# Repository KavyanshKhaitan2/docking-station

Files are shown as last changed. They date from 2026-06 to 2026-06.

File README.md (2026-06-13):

# (Overengineered) Laptop Docking Station!

  

  [View in OnShape](https://cad.onshape.com/documents/6c290d74c1d15daba79eec04/w/3858ccf09c2f651529fab3b7/e/cec4245d48316d051146b3ca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)

A very cool laptop docking station with 9 USB-A 2.0 ports!

<div id="contents">

1. [Why?](#why)
2. [What can it do?](#what-can-it-do)
3. [Fallout Zine](#fallout-zine)
4. [PCB](#pcb)
   - [Mainboard](#mainboard)
   - [Left Daughterboard](#left-daugtherboard)
5. [Schematic](#schematic)
   - [Mainboard](#mainboard-1)
   - [Left Daughterboard](#left-daugtherboard-1)
   - [Right Daugtherboard](#right-daugtherboard)
   - [Front Daugtherboard](#front-daughterboard)
6. [3D](#3d)
   - [Main case](#main-case)
   - [Macropad assembly](#macropad-assembly)
   - [Macropad case](#macropad-case)
   - [ePaper assembly](#epaper-assembly)
   - [ePaper case](#epaper-case)
7. [Bill of Materials](#bom)

</div>

## Why?
My laptop only has 2 USB-A ports, which is honestly not enough especially when both of them are used up for a keyboard and mouse.

I made this docking station to change that.

Another reason I made this is that I kinda like taking my laptop with me and keep it on my lap while using it on the sofa sometimes, so a docking station kinda makes that easier so you only have to plug it in and then everything works!

<div align="center"><a href="#contents">Jump to contents</a></div>

## What can it do?
It has 9 USB ports, which you can connect whatever you want to. The USB ports are controlled using an Fe1.1s controller.

It also has an ESP32 and 2 controllable PWM case fans (with two mosfet so you can turn them completely off), to keep your laptop cool and prevent it from overheating.

I also added external power from a barrel jack, because the laptop wont be able to power so many USB ports, especially when things are connected to them.

There is also a programmable e-ink display, you can display the time, your notifications, the current speed of the fans, or even show specifically which USB ports are currently in use!

I also added a mini detachable macropad with three switches and a rotary encoder.

You can program the macropad's buttons to do whatever you want! The rotary encoder also works as a switch, so technically there are four switches. You can make the rotary encoder change the volume, fan speeds, etc!

The macropad is connected to the ESP32!

Oh and btw the ESP32 also supports WiFi incase you want it to show weather or something even when the laptop is turned off.

The ESP32 also knows exactly which ports are connected to devices at a time, so you can also make it show how many ports are in use, and how many are free, etc!

<div align="center"><a href="#contents">Jump to contents</a></div>

## Fallout Zine
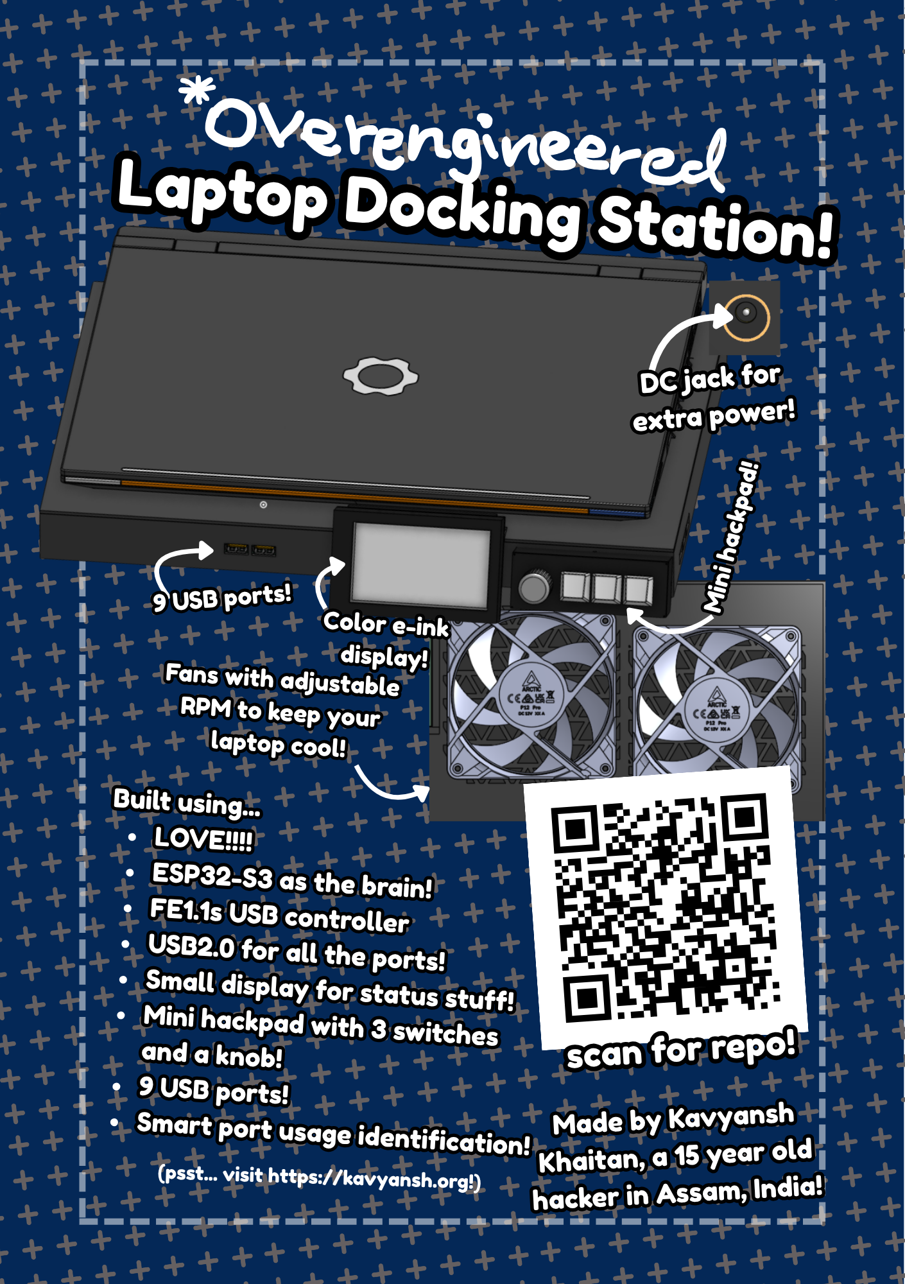
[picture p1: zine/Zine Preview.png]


[ [Download PDF](https://github.com/KavyanshKhaitan2/docking-station/raw/main/zine/Zine%20Print.pdf) ]

<div align="center"><a href="#contents">Jump to contents</a></div>

## PCB
<div align="center"><a href="https://kicanvas.org/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">View in KiCanvas</a></div>

### Mainboard


### Left Daugtherboard


The rest of the PCBs are very similar to the left daughterboard one, so I wont add them. If you still want to take a look at them, feel free to open the KiCanvas link!

<div align="center"><a href="#contents">Jump to contents</a></div>

## Schematic
<div align="center"><a href="https://kicanvas.org/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">View in KiCanvas</a></div>

### Mainboard


### Left daugtherboard


### Right daugtherboard


### Front daughterboard


<div align="center"><a href="#contents">Jump to contents</a></div>

## 3D
- [ [Download assembly as a STEP file](https://github.com/KavyanshKhaitan2/docking-station/blob/main/Final%20assembly.step) ]
- [ [Open Assembly in OnShape](https://cad.onshape.com/documents/6c290d74c1d15daba79eec04/w/3858ccf09c2f651529fab3b7/e/cec4245d48316d051146b3ca) ]

### Main case


- [View in OnShape](https://cad.onshape.com/documents/6c290d74c1d15daba79eec04/w/3858ccf09c2f651529fab3b7/e/84ca16973cb290fcea814d7e)
  - Part 1 (bottom) ([View STL in GitHub](https://github.com/KavyanshKhaitan2/docking-station/blob/main/production/3dp/Main%20Case/Main%20Case%20Thingy%20-%20Part%201.stl))
    - Print in black
    - Please print this part with supports!
  - Part 2 (top) ([View STL in GitHub](https://github.com/KavyanshKhaitan2/docking-station/blob/main/production/3dp/Main%20Case/Main%20Case%20Thingy%20-%20Part%202.stl))
    - Print in black

<div align="center"><a href="#contents">Jump to contents</a></div>

### Macropad assembly


- [View in OnShape](https://cad.onshape.com/documents/6c290d74c1d15daba79eec04/w/3858ccf09c2f651529fab3b7/e/eab1af3c6609ed024df62d84)

### Macropad case


- [View in OnShape](https://cad.onshape.com/documents/6c290d74c1d15daba79eec04/w/3858ccf09c2f651529fab3b7/e/cd5c69b8e6d2878261d109a7)
  - Part 1 (bottom) ([View STL in GitHub](https://github.com/KavyanshKhaitan2/docking-station/blob/main/production/3dp/Switches%20Case/Switches%20Case%20-%20Part%201.stl))
    - Print in black
  - Part 2 (top) ([View STL in GitHub](https://github.com/KavyanshKhaitan2/docking-station/blob/main/production/3dp/Switches%20Case/Switches%20Case%20-%20Part%202.stl))
    - Print in black
  - Screw ([View STL in GitHub](https://github.com/KavyanshKhaitan2/docking-station/blob/main/production/3dp/Switches%20Case/Switches%20Case%20-%20Screw%20(print%20x4).stl))
    - Print in black
    - Print x4
  - Accent (for top) ([View STL in GitHub](https://github.com/KavyanshKhaitan2/docking-station/blob/main/production/3dp/Switches%20Case/Switches%20Case%20-%20Accent.stl))
    - Print in filament closest to #8B2B2B.
      - 

<div align="center"><a href="#contents">Jump to contents</a></div>

### ePaper assembly


- [View in OnShape](https://cad.onshape.com/documents/6c290d74c1d15daba79eec04/w/3858ccf09c2f651529fab3b7/e/d050ad97f0686956ed070595)

### ePaper case


- Main part
  - [View in OnShape](https://cad.onshape.com/documents/6c290d74c1d15daba79eec04/w/3858ccf09c2f651529fab3b7/e/4e8279b7c40fa71bd8f46031)
  - Lid part (Lid) ([View STL in GitHub](https://github.com/KavyanshKhaitan2/docking-station/blob/main/production/3dp/ePaper%20Case/ePaper%20case%20-%20case-lid.stl))
  - Main part (Main) ([View STL in GitHub](https://github.com/KavyanshKhaitan2/docking-station/blob/main/production/3dp/ePaper%20Case/ePaper%20case%20-%20case-main.stl))
- Display angle-r
  - [View in OnShape](https://cad.onshape.com/documents/6c290d74c1d15daba79eec04/w/3858ccf09c2f651529fab3b7/e/b7b2b35c02b07108b093d455)
  - [View STL on GitHub](https://github.com/KavyanshKhaitan2/docking-station/blob/main/production/3dp/ePaper%20Case/Display%20angle-r%20-%20Part%201.stl)
    - Print in black
   
<div align="center"><a href="#contents">Jump to contents</a></div>

# BOM
The total BOM cost is ~167 USD.

- [ [View BOM.csv on GitHub](https://github.com/KavyanshKhaitan2/docking-station/blob/main/BOM.csv) ]
- [ [View BOM on Google Sheets (recommended)](https://docs.google.com/spreadsheets/d/10IkC0bF_AbRYA1OKs2MpRCw-cC0xSpxhRANUAgOrwtY/edit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) ]

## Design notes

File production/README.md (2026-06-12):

# Ordering PCBs
These gerber zip files were produced using JLCPCB Toolkit in KiCAD, so it is recommended to order the PCBs from JLCPCB.
- All green
- All 2 layer boards
- All 1.6mm thick

# Printing the 3D models
- The Main Case, which is split in 2 parts, is printed in all black.
- - You may need to use some supports to print it properly, in which case, please do!
- The ePaper case contains two sub-modules
- - The Display angle-r (to connect the ePaper case with the Main Case at an angle)
- - - This part can be printed sideways so its efficient.
- - The ePaper case (the actual case)
- - Both have to be printed in all black.
- Switches Case
- - The "Part 1" and "Part 2" parts are printed in all-black.
- - The "Screw" part has to be printed 4 times in all-black.
- - The "Accent" part has to be printed in the accent colored filament, which should ideally be closest to this hex color: #8B2B2B

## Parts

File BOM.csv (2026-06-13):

Item name | Description | Link | Unit Price (USD) | MOQ | Qty | Qty to order | Amount | Running total | Item for
TYPE-C-31-M-12 | Type C receptacle | https://www.lcsc.com/product-detail/C165948.html | 0.1870 | 5 | 2 | 5 | 0.9350 | 0.94 | Mainboard
DC022B | Barrel Jack receptacle | https://www.lcsc.com/product-detail/C668599.html | 0.1563 | 5 | 1 | 5 | 0.7815 | 1.72 | Mainboard
S3-WROOM-1-N8 | MCU module | https://www.lcsc.com/product-detail/C2913198.html | 4.7733 | 1 | 1 | 1 | 4.7733 | 6.49 | Mainboard
FE1.1s-BSOP28BCNTR | USB controller | https://www.lcsc.com/product-detail/C42383361.html | 0.7039 | 1 | 3 | 3 | 2.1117 | 8.60 | Mainboard
CL31B104KBCNNNC | 0.1uF 1206 cap | https://www.lcsc.com/product-detail/C97946.html | 0.0190 | 20 | 21 | 40 | 0.7600 | 9.36 | Mainboard
T49S12MLDBE2X | Crystal 12MHz 20pF | https://www.lcsc.com/product-detail/C19189932.html | 0.0754 | 10 | 3 | 10 | 0.7540 | 10.12 | Mainboard
RT1206BRD075KL | RES 5kΩ ±1% 1206 | https://www.lcsc.com/product-detail/C870818.html | 0.0635 | 10 | 3 | 10 | 0.6350 | 10.75 | Mainboard
FRC1206F2701TS | RES 2.7kΩ ±1% 1206 | https://www.lcsc.com/product-detail/C2930416.html | 0.0044 | 100 | 3 | 100 | 0.4400 | 11.19 | Mainboard
B3F-4005 | Tactile Switch | https://www.lcsc.com/product-detail/C397283.html | 0.1612 | 5 | 1 | 5 | 0.8060 | 12.00 | Mainboard
FRC1206F5101TS | RES 5.1kΩ ±1% 1206 | https://www.lcsc.com/product-detail/C2933721.html | 0.0042 | 100 | 4 | 100 | 0.4200 | 12.42 | Mainboard
LM1117F-3.3 | 3V3 @ 1A L.D.O | https://www.lcsc.com/product-detail/C126019.html | 0.1849 | 5 | 1 | 5 | 0.9245 | 13.34 | Mainboard
AMS1117-1.8V | 1V8 @ 1A L.D.O | https://www.lcsc.com/product-detail/C5120766.html | 0.0531 | 10 | 1 | 10 | 0.5310 | 13.87 | Mainboard
Arctic P12 Slim | Case fan | https://www.amazon.in/ARCTIC-P12-Slim-PWM-Pressure-optimised/dp/B08QDKGCCW | 10.0000 | 1 | 2 | 2 | 20.0000 | 33.87 | Mainboard
RC1206FR-0710KL | RES 10kΩ ±1% 1206 | https://www.lcsc.com/product-detail/C132649.html | 0.0053 | 100 | 2 | 100 | 0.5300 | 34.40 | Mainboard
IRLZ44N(UMW) | N-Channel MOSFET | https://www.lcsc.com/product-detail/C42370423.html | 0.3353 | 5 | 2 | 5 | 1.6765 | 36.08 | Mainboard
B9B-PH-K-S(LF)(SN) | For E-Ink display | https://www.lcsc.com/product-detail/C157968.html | 0.1182 | 5 | 2 | 5 | 0.5910 | 36.67 | Mainboard
3.7inch e-Paper HAT+ | E-Ink display | https://www.amazon.in/3-7inch-Resolution-Interface-Compatible-Raspberry/dp/B0FCMBNR46 | 72.0000 | 1 | 1 | 1 | 72.0000 | 108.67 | Mainboard
GRM188R71A225KE15D | CAP CER 2.2uF 10V X7R 0603 | https://www.lcsc.com/product-detail/C86018.html | 0.0461 | 20 | 1 | 20 | 0.9220 | 109.59 | Buck Converter
GRM155R71A104KA01D | CAP CER 100nF 10V X7R 0402 | https://www.lcsc.com/product-detail/C71687.html | 0.0045 | 100 | 2 | 100 | 0.4500 | 110.04 | Buck Converter
GRM21BR61A226ME44L | CAP CER 22uF 10V X5R 0805 | https://www.lcsc.com/product-detail/C441864.html | 0.1006 | 5 | 1 | 5 | 0.5030 | 110.54 | Buck Converter
FRC1206F1003TS | RES 100kΩ ±1% 250mW 1206 | https://www.lcsc.com/product-detail/C2907368.html | 0.0043 | 100 | 1 | 100 | 0.4300 | 110.97 | Buck Converter
XAL5020-561MEC | FIXED IND 560nH SMD,5.4x5.2mm | https://www.lcsc.com/product-detail/C20623488.html | 1.7578 | 1 | 1 | 1 | 1.7578 | 112.73 | Buck Converter
CSD17579Q5A | MOSFET N-CH 30V 46A VSONP-8(5x6) | https://www.lcsc.com/product-detail/C2760461.html | 0.4784 | 5 | 2 | 5 | 2.3920 | 115.12 | Buck Converter
GRM31CR71E335KA88L | CAP CER 3.3uF 25V X7R 1206 | https://www.lcsc.com/product-detail/C668366.html | 0.2513 | 5 | 2 | 5 | 1.2565 | 116.38 | Buck Converter
CSD17579Q5A | MOSFET N-CH 30V 46A VSONP-8(5x6) | https://www.lcsc.com/product-detail/C2760461.html | 0.4784 | 1 | 1 | 1 | 0.4784 | 116.86 | Buck Converter
LM5148RGYR | 80-V Synchronous Buck DC/DC Controller | https://www.lcsc.com/product-detail/C7470701.html | 0.9316 | 2 | 1 | 2 | 1.8632 | 118.72 | Buck Converter
1RC1206F9538 | 250mW 9.53Ω 200V Thick Film Resistor ±1% ±400ppm/℃ 1206 Chip Resistor - Surface Mount RoHS | https://www.lcsc.com/product-detail/C54533007.html | 0.0032 | 100 | 1 | 100 | 0.3200 | 119.04 | Buck Converter
WSLP12066L000FEA | RES 6mΩ ±1% 1W 1206 | https://www.lcsc.com/product-detail/C2090290.html | 0.1782 | 5 | 1 | 5 | 0.8910 | 119.93 | Buck Converter
FRC1206F4022TS | RES 40.2kΩ ±1% 250mW 1206 | https://www.lcsc.com/product-detail/C5159734.html | 0.0041 | 100 | 1 | 100 | 0.4100 | 120.34 | Buck Converter
06031U6R8BAT2A | 6.8pF 100V 0603 Ceramic Capacitors RoHS | https://www.lcsc.com/product-detail/C5259058.html | 0.2691 | 2 | 1 | 2 | 0.5382 | 120.88 | Buck Converter
CL21C222JBFNNNE | CAP CER 2.2nF 50V C0G 0805 | https://www.lcsc.com/product-detail/C28260.html | 0.0289 | 10 | 1 | 10 | 0.2890 | 121.17 | Buck Converter
FRC1206F2801TS | RES 2.8kΩ ±1% 250mW 1206 | https://www.lcsc.com/product-detail/C5126233.html | 0.0042 | 100 | 1 | 100 | 0.4200 | 121.59 | Buck Converter
FRC1206F2432TS | RES 24.3kΩ ±1% 250mW 1206 | https://www.lcsc.com/product-detail/C2933651.html | 0.0043 | 100 | 2 | 100 | 0.4300 | 122.02 | Buck Converter
MOLEX 2005280040 | CONN FFC FPC 4POS 1mm BOTTOM CNT SMD R/A | https://www.lcsc.com/product-detail/C563728.html | 0.2335 | 5 | 4 | 5 | 1.1675 | 123.19 | MB, LB, FB
AFA07-S06ECA-00 | CONN FFC FPC 6POS 1mm TOP CNT SMD R/A | https://www.lcsc.com/product-detail/C262733.html | 0.1105 | 5 | 2 | 5 | 0.5525 | 123.74 | MB, RB
USB1046-GF-0190-L-B-A | USB Receptacle, Type A, 4 Pin, SMT, Horizontal | https://www.lcsc.com/product-detail/C6307429.html | 0.8497 | 2 | 7 | 8 | 6.7976 | 130.54 | Mainboard
JS10B-04P-150-4-8 | CABLE FFC/FPC 4POS 1mm | https://www.lcsc.com/product-detail/C2857773.html | 0.1021 | 5 | 1 | 5 | 0.5105 | 131.05 | Left Board
JS10B-04P-150-4-8 | CABLE FFC/FPC 4POS 1mm | https://www.lcsc.com/product-detail/C2857773.html | 0.1021 | 5 | 1 | 5 | 0.5105 | 131.56 | Front Board
1.0*6P*400*B*4/4*8/8 | 0.3mm 6P 1mm Reverse 40cm P=1mm Flat Flex Cables (FFC, FPC) RoHS | https://www.lcsc.com/product-detail/C54350058.html | 0.0848 | 5 | 1 | 5 | 0.4240 | 131.98 | Right Board
PEC11R-4020F-S0024 | Through Hole Encoders RoHS | https://www.lcsc.com/product-detail/C143788.html | 3.1835 | 1 | 1 | 1 | 3.1835 | 135.17 | Front Panel
CPG151101D13 | Blue Switch 12V 50gf Through Hole Pushbutton Switches RoHS | https://www.lcsc.com/product-detail/C49234235.html | 0.1065 | 5 | 4 | 5 | 0.5325 | 135.70 | Front Panel
USB1046-GF-0190-L-B-A | USB Receptacle, Type A, 4 Pin, SMT, Horizontal | https://www.lcsc.com/product-detail/C6307429.html | 0.8497 | 2 | 2 | 2 | 1.6994 | 137.40 | Front Panel
2.54-1*4P | CONN SOCKET 4POS 2.54mm SINGLE ROW TH | https://www.lcsc.com/product-detail/C2718488.html | 0.0783 | 10 | 1 | 10 | 0.7830 | 138.18 | Front Panel
PM2.54-1X2PM-H85 | CONN SOCKET 2POS 2.54mm SINGLE ROW TH | https://www.lcsc.com/product-detail/C42431841.html | 0.0767 | 5 | 1 | 5 | 0.3835 | 138.57 | Front Panel
USB1046-GF-0190-L-B-A | USB Receptacle, Type A, 4 Pin, SMT, Horizontal | https://www.lcsc.com/product-detail/C6307429.html | 0.8497 | 2 | 2 | 2 | 1.6994 | 140.26 | Left Panel
USB1046-GF-0190-L-B-A | USB Receptacle, Type A, 4 Pin, SMT, Horizontal | https://www.lcsc.com/product-detail/C6307429.html | 0.8497 | 2 | 3 | 4 | 3.3988 | 143.66 | Right Panel
Power Cables | qty. in metres | https://robu.in/product/12awg-solid-core-insulated-wire-silicone-black/ | 1.5000 | 1 | 10 | 10 | 15.0000 | 158.66 | For power
PCBs | qty. in 5 PCBs | https://jlcpcb.com | 2.0000 | 1 | 4 | 4 | 8.0000 | 166.66 | Just PCBs lol

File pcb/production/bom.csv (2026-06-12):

Designator | Footprint | Quantity | Value | LCSC Part #
C1, C10, C11, C12, C13, C14, C15, C16, C18, C2, C24, C25, C29, C3, C4, C5, C6, C7, C8, C9 | 1206 | 20 | 0.1uF
C17 | 0603 | 1 | 2.2uF|9mΩ
C19, C23 | 1206 | 2 | 3.4uF|4.66mΩ
C20 | 0805 | 1 | 2.2nF
C21 | 0603 | 1 | 6.8pF
C22, C28 | 0402 | 2 | 100nF|1mΩ
C26 | 0805 | 1 | 22uF|3mΩ
J10 | JUSHUO_AFA07-S06FCA-00_1x6-1MP_P1.0mm_Horizontal | 1 | Conn_01x06
J11 | PinHeader_1x06_P2.54mm_Vertical | 1 | Conn_01x06
J15, J19 | USB_C_Receptacle_HRO_TYPE-C-31-M-12 | 2 | USB_C_Receptacle_USB2.0_16P
J2 | SolderWire-4sqmm_1x02_P12mm_D3mm_OD6mm | 1 | DC022B (external)
J20, J24, J27 | SolderWire-4sqmm_1x02_P12mm_D3mm_OD6mm | 3 | Conn_01x02
J21, J25 | Molex_200528-0040_1x04-1MP_P1.00mm_Horizontal | 2 | Conn_01x04
J4 | JST_PH_B9B-PH-K_1x09_P2.00mm_Vertical | 1 | Conn_01x09
J5, J7 | USB_A_Receptacle_GCT_USB1046 | 2 | USB_A
L2 | L_Coilcraft_XAL5020-XXX | 1 | 560nH|8.3mΩ
M1, M2 | FanPinHeader_1x04_P2.54mm_Vertical | 2 | Fan_4pin
Q1, Q2 | TDSON-8-1 | 2 | CSD17579Q5A
Q3, Q4 | TO-220-3_Vertical | 2 | IRLZ44N
R1, R6, R8 | 1206 | 3 | 2.7k±1%
R10 | 1206 | 1 | 24.3k
R11 | 1206 | 1 | 2.8k
R12 | 1206 | 1 | 6m
R13, R14 | 1206 | 2 | 10k
R15, R16, R17, R18, R21 | 1206 | 5 | 5.1k
R19, R20 | 1206 | 2 | 1k
R22, R5, R7 | 1206 | 3 | 5k±10%
R3 | 1206 | 1 | 40.2k
R4 | 1206 | 1 | 9.53k
R9 | 1206 | 1 | 100k
SW1 | SW_SPST_Omron_B3F-50xx | 1 | SW_SPST
U1, U5, U6 | SSOP-28_3.9x9.9mm_P0.635mm | 3 | FE1.1s
U2 | SOT-89-3_Handsoldering | 1 | LM1117F-3.3
U3 | SOT-89-3_Handsoldering | 1 | AMS1117-1.8
U4 | ESP32-S3-WROOM-1 | 1 | ESP32-S3-WROOM-1
U7 | Texas_RGY_R-PVQFN-N24_EP2.05x3.1mm_ThermalVias | 1 | LM5148RGYR
Y1, Y3, Y4 | Crystal_HC49-4H_Vertical | 3 | T49S12MLDBE2X

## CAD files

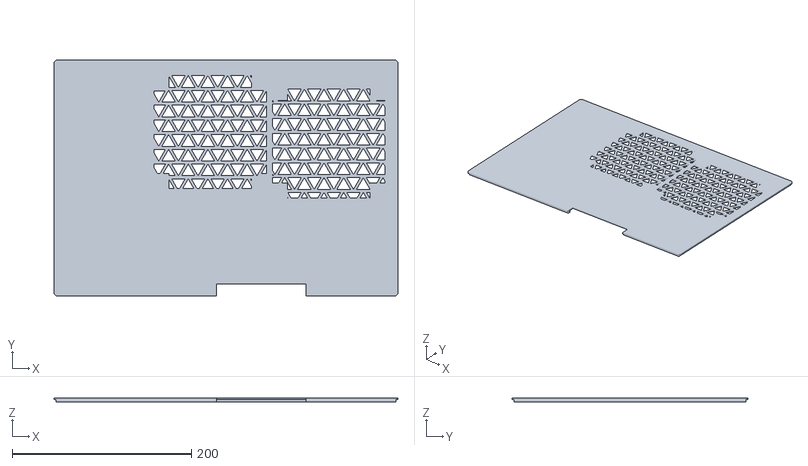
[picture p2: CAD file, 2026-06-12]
production/3dp/Main Case/Main Case Thingy - Part 2.stl
383.9 x 263.5 x 5.00

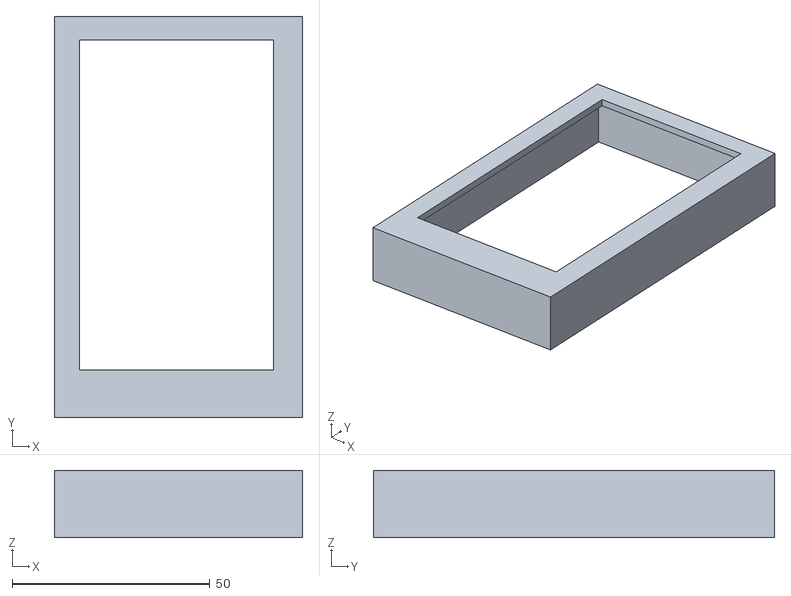
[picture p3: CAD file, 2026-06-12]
production/3dp/ePaper Case/ePaper case - case-main.stl
62.7 x 101.5 x 17.0

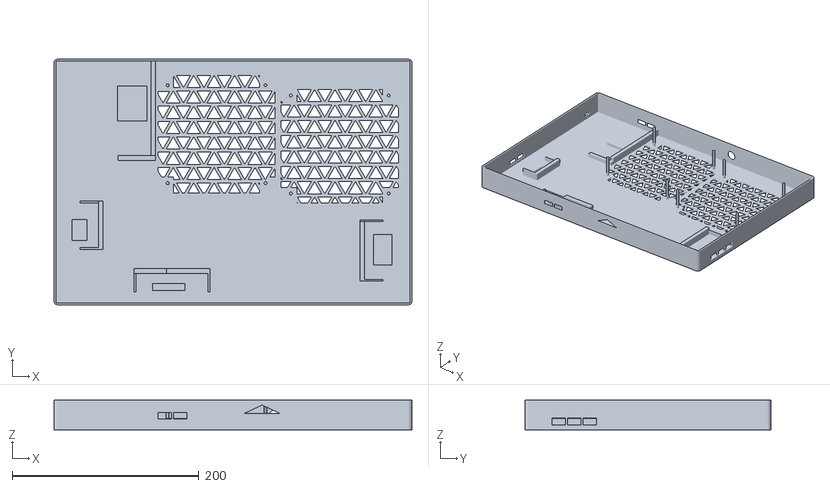
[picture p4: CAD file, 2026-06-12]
production/3dp/Main Case/Main Case Thingy - Part 1.stl
383.9 x 263.5 x 32.0

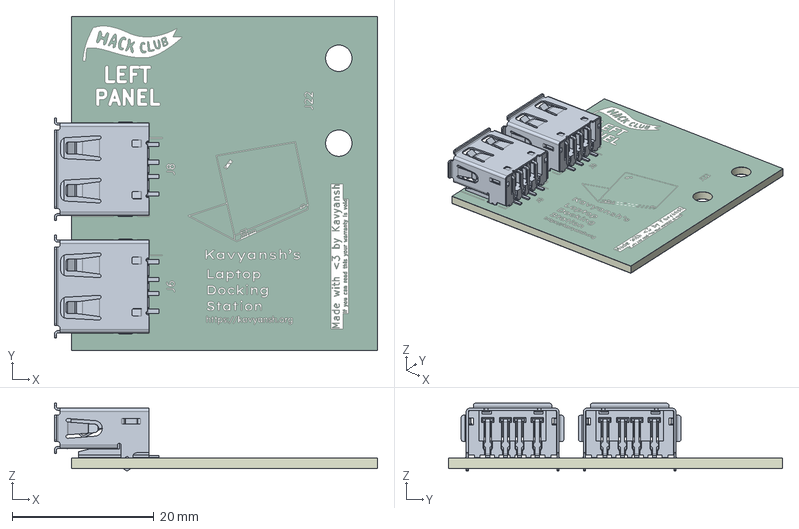
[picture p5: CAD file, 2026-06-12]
pcb/pcb_3dm/daughterboard-left.step
45.7 x 47.2 x 9.55 mm
USB1046-GF-0190-L-B-A_PART1 x 2
USB1046-GF-0190-L-B-A_PART2 x 2
USB1046-GF-0190-L-B-A_PART3 x 8
daughterboard-left_silkscreen x 2
daughterboard-left_soldermask x 2
daughterboard-left_PCB

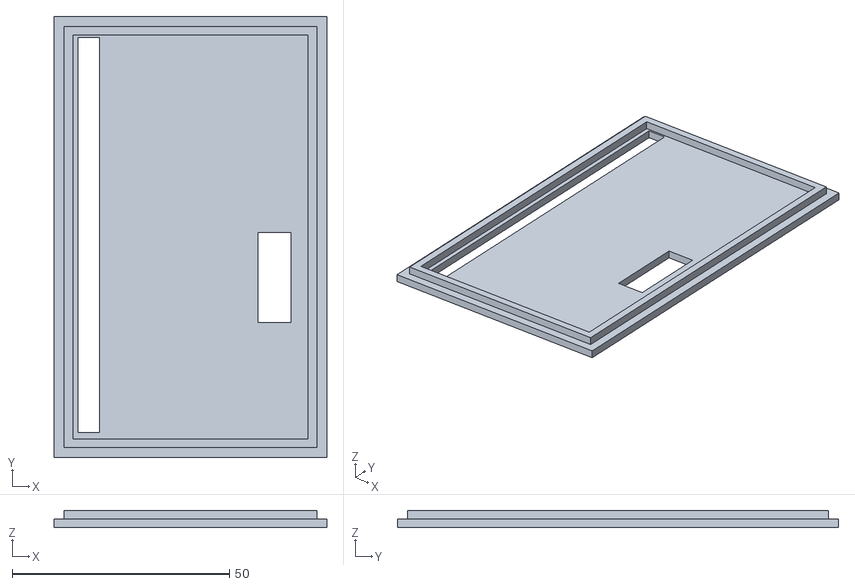
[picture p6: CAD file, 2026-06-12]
production/3dp/ePaper Case/ePaper case - case-lid.stl
62.7 x 101.5 x 4.00

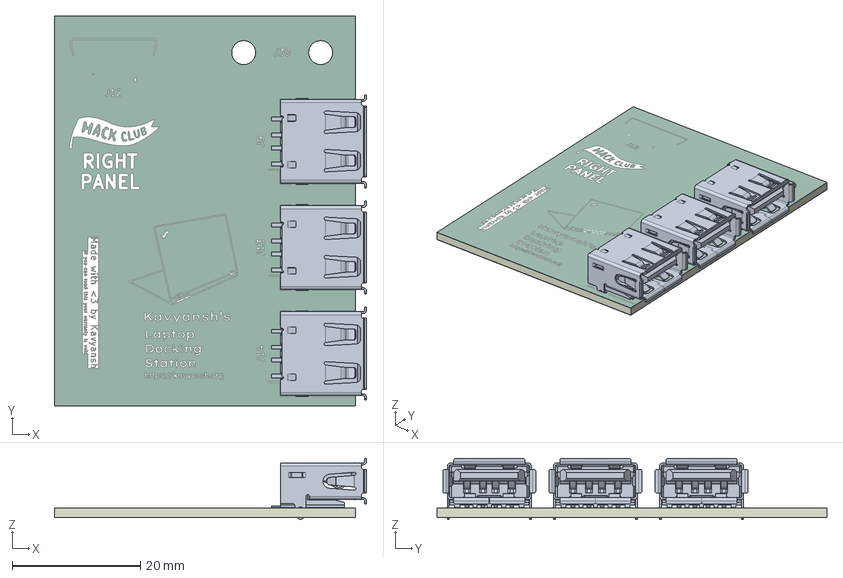
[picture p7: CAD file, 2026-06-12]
pcb/pcb_3dm/daughterboard-right.step
48.7 x 60.8 x 9.55 mm
USB1046-GF-0190-L-B-A_PART1 x 3
USB1046-GF-0190-L-B-A_PART2 x 3
USB1046-GF-0190-L-B-A_PART3 x 12
daughterboard-right_silkscreen x 2
daughterboard-right_soldermask x 2
daughterboard-right_PCB

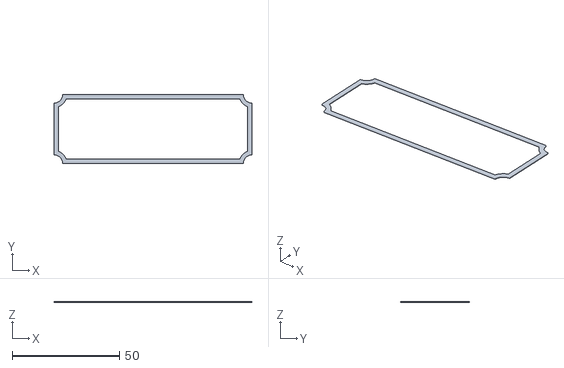
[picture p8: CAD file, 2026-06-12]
production/3dp/Switches Case/Switches Case - Accent.stl
92.2 x 32.1 x 0.5

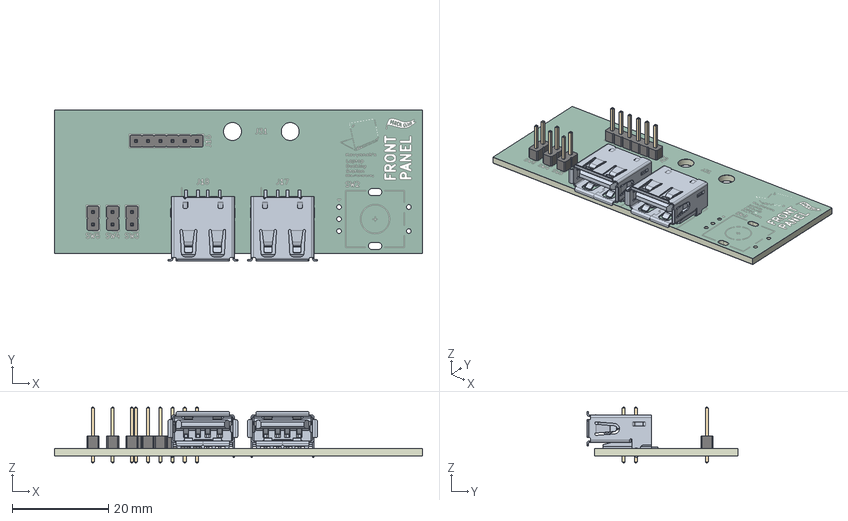
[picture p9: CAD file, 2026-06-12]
pcb/pcb_3dm/daughterboard-front.step
76.5 x 31.5 x 11.5 mm
PinHeader_1x02_P254mm_Vertical x 3
USB1046-GF-0190-L-B-A_PART1 x 2
USB1046-GF-0190-L-B-A_PART2 x 2
USB1046-GF-0190-L-B-A_PART3 x 8
PinHeader_1x06_P254mm_Vertical
daughterboard-front_silkscreen x 2
daughterboard-front_soldermask x 2
daughterboard-front_PCB

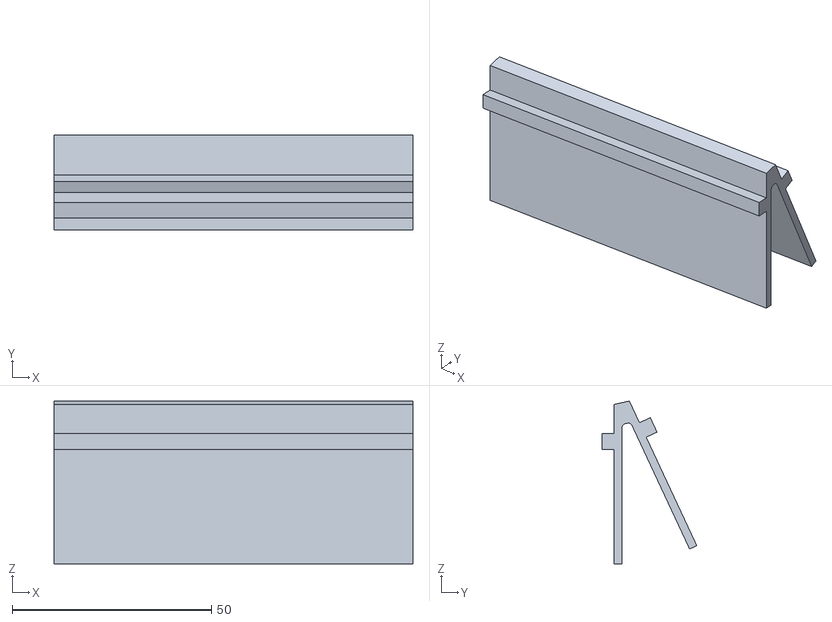
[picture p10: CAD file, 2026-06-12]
production/3dp/ePaper Case/Display angle-r - Part 1.stl
90.0 x 23.7 x 40.8

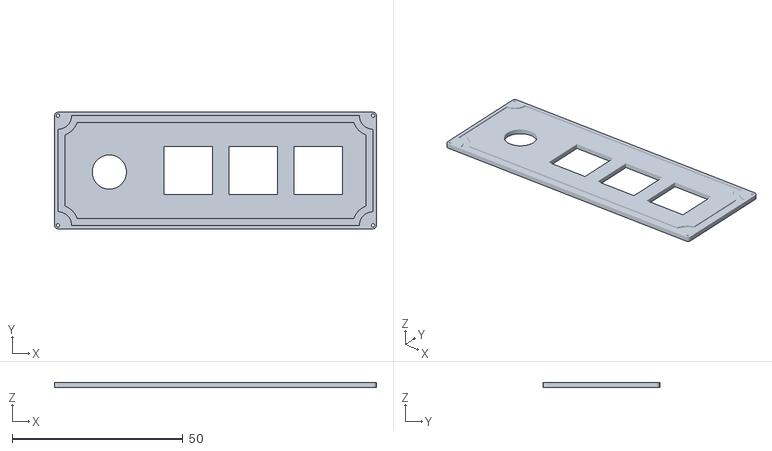
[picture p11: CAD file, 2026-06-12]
production/3dp/Switches Case/Switches Case - Part 2.stl
94.2 x 34.1 x 1.50

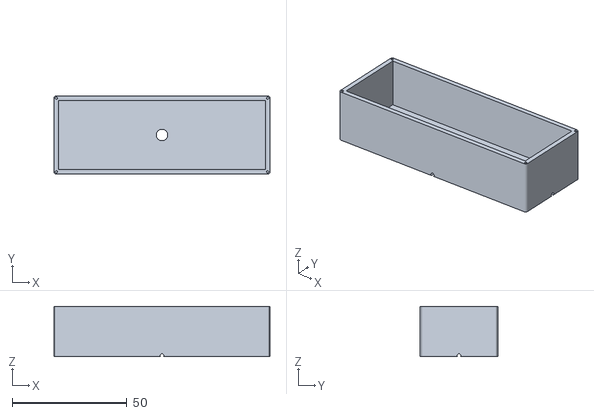
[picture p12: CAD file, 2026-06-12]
production/3dp/Switches Case/Switches Case - Part 1.stl
94.2 x 34.1 x 22.0

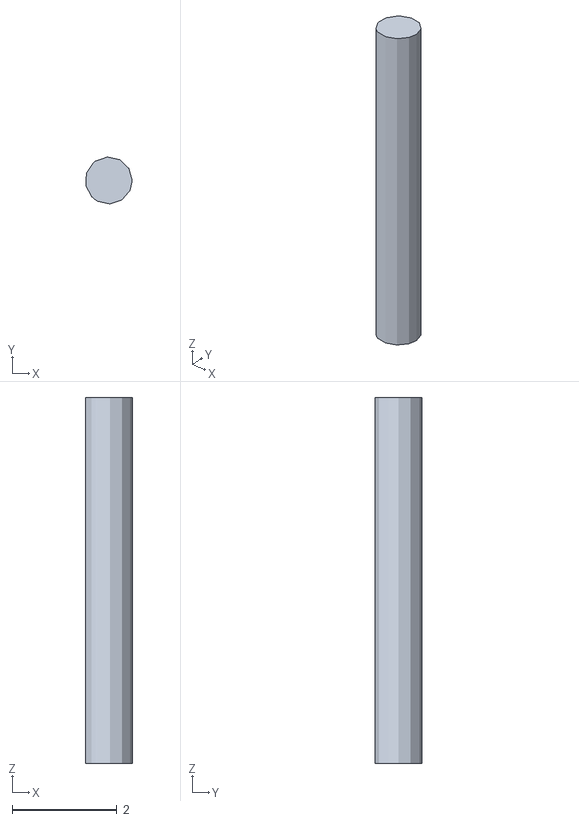
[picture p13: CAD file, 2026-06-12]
production/3dp/Switches Case/Switches Case - Screw (print x4).stl
0.889 x 0.899 x 7.00

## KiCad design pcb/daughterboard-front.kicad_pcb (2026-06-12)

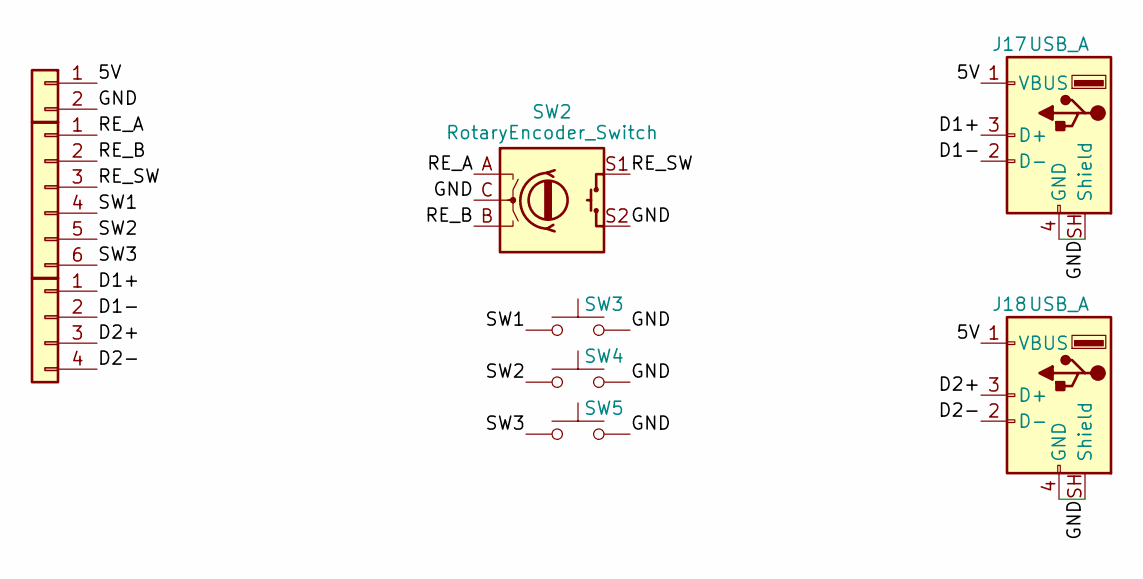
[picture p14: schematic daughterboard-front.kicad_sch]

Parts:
J16: Conn_01x06; PinHeader_1x06_P2.54mm_Vertical
J17, J18: USB_A; USB_A_Receptacle_GCT_USB1046
J26: Conn_01x04; Molex_200528-0040_1x04-1MP_P1.00mm_Horizontal
J31: Conn_01x02; SolderWire-4sqmm_1x02_P12mm_D3mm_OD6mm
SW2: RotaryEncoder_Switch; RotaryEncoder_Alps_EC11E-Switch_Vertical_H20mm
SW3, SW4, SW5: SW_Push; PinHeader_1x02_P2.54mm_Vertical

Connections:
/5V: J17.1 (VBUS), J18.1 (VBUS), J31.1
/D1+: J17.3 (D+), J26.1
/D1-: J17.2 (D-), J26.2
/D2+: J18.3 (D+), J26.3
/D2-: J18.2 (D-), J26.4
/GND: J17.4 (GND), J17.SH (Shield), J18.4 (GND), J18.SH (Shield), J31.2, SW2.C, SW2.S2, SW3.1, SW4.1, SW5.1
/RE_A: J16.1, SW2.A
/RE_B: J16.2, SW2.B
/RE_SW: J16.3, SW2.S1
/SW1: J16.4, SW3.2
/SW2: J16.5, SW4.2
/SW3: J16.6, SW5.2

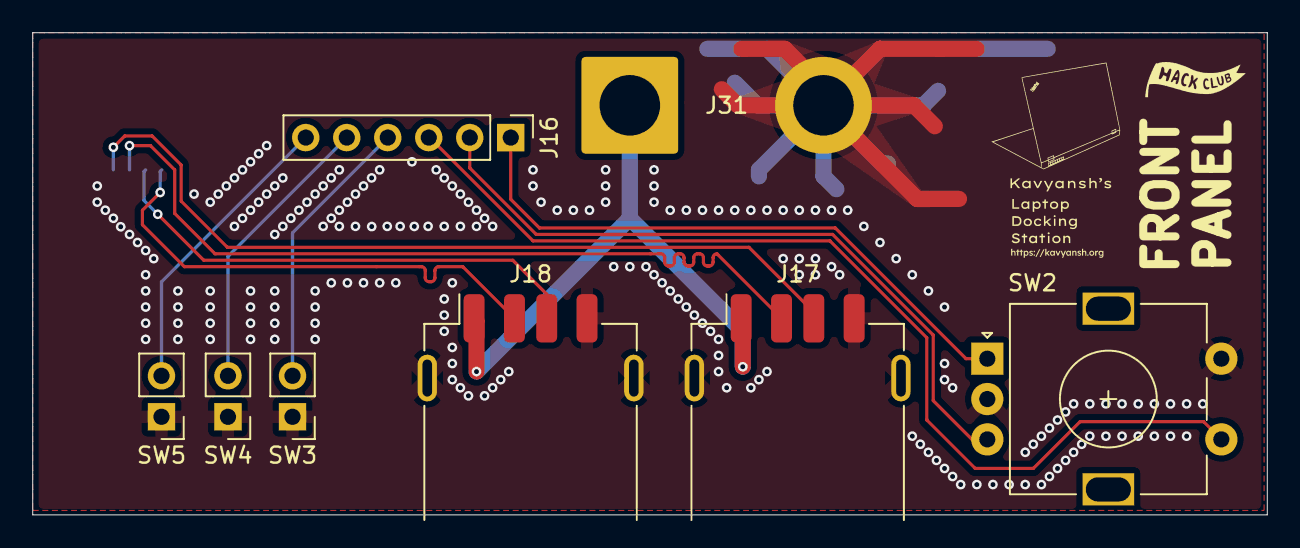
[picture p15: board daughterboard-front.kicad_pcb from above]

Board: 2 copper layers, 76.5 x 29.9 mm, 9 parts (1 on the bottom side), 12 nets.

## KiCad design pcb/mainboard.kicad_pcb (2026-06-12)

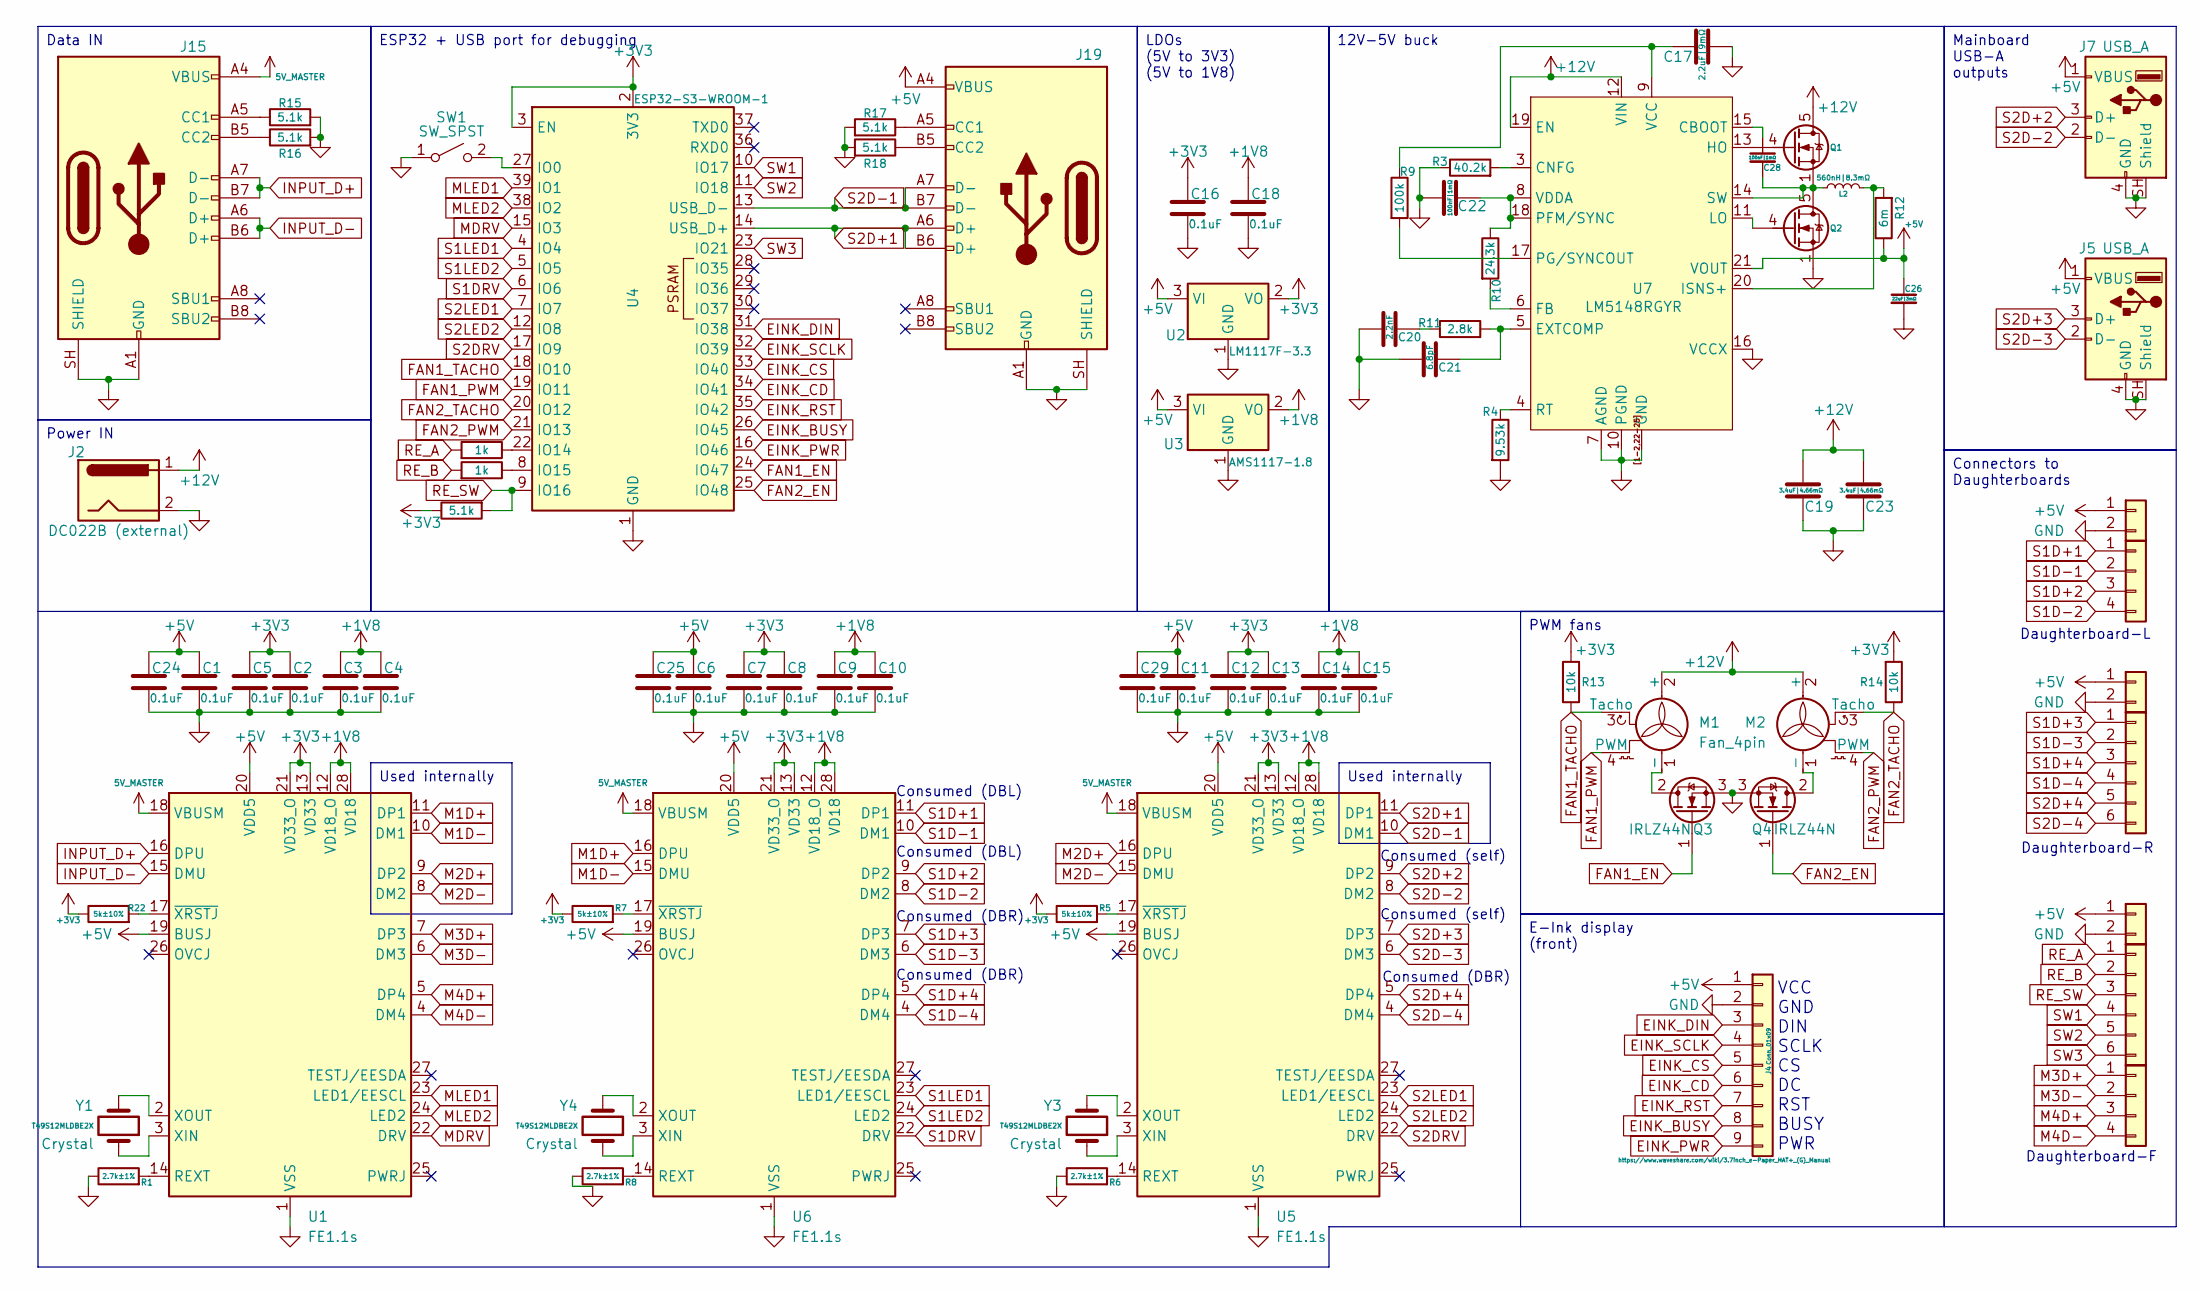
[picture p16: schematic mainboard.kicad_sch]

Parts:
C1, C2, C3, C4, C5, C6, C7, C8, C9, C10, C11, C12, C13, C14, C15, C16, C18, C24, C25, C29: 0.1uF; C_1206_3216Metric_Pad1.33x1.80mm_HandSolder
C17: 2.2uF|9mΩ; C_0603_1608Metric_Pad1.08x0.95mm_HandSolder
C19, C23: 3.4uF|4.66mΩ; C_1206_3216Metric_Pad1.33x1.80mm_HandSolder
C20: 2.2nF; C_0805_2012Metric_Pad1.18x1.45mm_HandSolder
C21: 6.8pF; C_0603_1608Metric_Pad1.08x0.95mm_HandSolder
C22, C28: 100nF|1mΩ; C_0402_1005Metric_Pad0.74x0.62mm_HandSolder
C26: 22uF|3mΩ; C_0805_2012Metric_Pad1.18x1.45mm_HandSolder
J2: DC022B (external); SolderWire-4sqmm_1x02_P12mm_D3mm_OD6mm
J4: Conn_01x09; JST_PH_B9B-PH-K_1x09_P2.00mm_Vertical
J5, J7: USB_A; USB_A_Receptacle_GCT_USB1046
J10: Conn_01x06; JUSHUO_AFA07-S06FCA-00_1x6-1MP_P1.0mm_Horizontal
J11: Conn_01x06; PinHeader_1x06_P2.54mm_Vertical
J15, J19: USB_C_Receptacle_USB2.0_16P; USB_C_Receptacle_HRO_TYPE-C-31-M-12
J20, J24, J27: Conn_01x02; SolderWire-4sqmm_1x02_P12mm_D3mm_OD6mm
J21, J25: Conn_01x04; Molex_200528-0040_1x04-1MP_P1.00mm_Horizontal
L2: 560nH|8.3mΩ; L_Coilcraft_XAL5020-XXX
M1, M2: Fan_4pin; FanPinHeader_1x04_P2.54mm_Vertical
Q1, Q2: CSD17579Q5A; TDSON-8-1
Q3, Q4: IRLZ44N; TO-220-3_Vertical
R1, R6, R8: 2.7k±1%; R_1206_3216Metric_Pad1.30x1.75mm_HandSolder
R3: 40.2k; R_1206_3216Metric_Pad1.30x1.75mm_HandSolder
R4: 9.53k; R_1206_3216Metric_Pad1.30x1.75mm_HandSolder
R5, R7, R22: 5k±10%; R_1206_3216Metric_Pad1.30x1.75mm_HandSolder
R9: 100k; R_1206_3216Metric_Pad1.30x1.75mm_HandSolder
R10: 24.3k; R_1206_3216Metric_Pad1.30x1.75mm_HandSolder
R11: 2.8k; R_1206_3216Metric_Pad1.30x1.75mm_HandSolder
R12: 6m; R_1206_3216Metric_Pad1.30x1.75mm_HandSolder
R13, R14: 10k; R_1206_3216Metric_Pad1.30x1.75mm_HandSolder
R15, R16, R17, R18, R21: 5.1k; R_1206_3216Metric_Pad1.30x1.75mm_HandSolder
R19, R20: 1k; R_1206_3216Metric_Pad1.30x1.75mm_HandSolder
SW1: SW_SPST; SW_SPST_Omron_B3F-50xx
U1, U5, U6: FE1.1s; SSOP-28_3.9x9.9mm_P0.635mm
U2: LM1117F-3.3; SOT-89-3_Handsoldering
U3: AMS1117-1.8; SOT-89-3_Handsoldering
U4: ESP32-S3-WROOM-1
U7: LM5148RGYR; Texas_RGY_R-PVQFN-N24_EP2.05x3.1mm_ThermalVias
Y1, Y3, Y4: T49S12MLDBE2X; Crystal_HC49-4H_Vertical

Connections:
5V_MASTER: J15.A4 (VBUS), J15.A9 (VBUS), J15.B4 (VBUS), J15.B9 (VBUS), U1.18 (VBUSM), U5.18 (VBUSM), U6.18 (VBUSM)
+1V8: C3.1, C4.1, C9.1, C10.1, C14.1, C15.1, C18.1, U1.12 (VD18_O), U1.28 (VD18), U3.2 (VO), U5.12 (VD18_O), U5.28 (VD18), U6.12 (VD18_O), U6.28 (VD18)
+3V3: C2.1, C5.1, C7.1, C8.1, C12.1, C13.1, C16.1, R5.1, R7.1, R13.2, R14.2, R21.1, R22.1, U1.13 (VD33), U1.21 (VD33_O), U2.2 (VO), U4.2 (3V3), U4.3 (EN), U5.13 (VD33), U5.21 (VD33_O), U6.13 (VD33), U6.21 (VD33_O)
+5V: C1.1, C6.1, C11.1, C24.1, C25.1, C26.1, C29.1, J4.1, J5.1 (VBUS), J7.1 (VBUS), J19.A4 (VBUS), J19.A9 (VBUS), J19.B4 (VBUS), J19.B9 (VBUS), J20.1, J24.1, J27.1, R12.1, U1.19 (BUSJ), U1.20 (VDD5), U2.3 (VI), U3.3 (VI), U5.19 (BUSJ), U5.20 (VDD5), U6.19 (BUSJ), U6.20 (VDD5), U7.21 (VOUT)
+12V: C19.2, C23.2, J2.1, M1.2 (+), M2.2 (+), Q1.5 (D), U7.12 (VIN), U7.19 (EN)
EINK_BUSY: J4.8, U4.26 (IO45)
EINK_CD: J4.6, U4.34 (IO41)
EINK_CS: J4.5, U4.33 (IO40)
EINK_DIN: J4.3, U4.31 (IO38)
EINK_PWR: J4.9, U4.16 (IO46)
EINK_RST: J4.7, U4.35 (IO42)
EINK_SCLK: J4.4, U4.32 (IO39)
FAN1_EN: Q3.1 (G), U4.24 (IO47)
FAN1_PWM: M1.4 (PWM), U4.19 (IO11)
FAN1_TACHO: M1.3 (Tacho), R13.1, U4.18 (IO10)
FAN2_EN: Q4.1 (G), U4.25 (IO48)
FAN2_PWM: M2.4 (PWM), U4.21 (IO13)
FAN2_TACHO: M2.3 (Tacho), R14.1, U4.20 (IO12)
GND: C1.2, C2.2, C3.2, C4.2, C5.2, C6.2, C7.2, C8.2, C9.2, C10.2, C11.2, C12.2, C13.2, C14.2, C15.2, C16.2, C17.1, C18.2, C19.1, C20.2, C21.2, C22.2, C23.1, C24.2, C25.2, C26.2, C29.2, J2.2, J4.2, J5.4 (GND), J5.SH (Shield), J7.4 (GND), J7.SH (Shield), J15.A1 (GND), J15.A12 (GND), J15.B1 (GND), J15.B12 (GND), J15.SH (SHIELD), J19.A1 (GND), J19.A12 (GND), J19.B1 (GND), J19.B12 (GND), J19.SH (SHIELD), J20.2, J24.2, J27.2, Q2.1 (S), Q2.2 (S), Q2.3 (S), Q3.3 (S), Q4.3 (S), R1.1, R3.1, R4.2, R6.1, R8.1, R15.2, R16.2, R17.2, R18.2, SW1.1 (A), U1.1 (VSS), U2.1 (GND), U3.1 (GND), U4.1 (GND), U4.40 (GND), U4.41 (GND), U5.1 (VSS), U6.1 (VSS), U7.1 (GND), U7.2 (GND), U7.7 (AGND), U7.10 (PGND), U7.16 (VCCX), U7.22 (GND), U7.23 (GND), U7.24 (GND), U7.25 (GND), U7.[1-2,22-25] (GND)
INPUT_D+: J15.A7 (D-), J15.B7 (D-), U1.16 (DPU)
INPUT_D-: J15.A6 (D+), J15.B6 (D+), U1.15 (DMU)
M1D+: U1.11 (DP1), U6.16 (DPU)
M1D-: U1.10 (DM1), U6.15 (DMU)
M2D+: U1.9 (DP2), U5.16 (DPU)
M2D-: U1.8 (DM2), U5.15 (DMU)
M3D+: J25.1, U1.7 (DP3)
M3D-: J25.2, U1.6 (DM3)
M4D+: J25.3, U1.5 (DP4)
M4D-: J25.4, U1.4 (DM4)
MDRV: U1.22 (DRV), U4.15 (IO3)
MLED1: U1.23 (LED1/EESCL), U4.39 (IO1)
MLED2: U1.24 (LED2), U4.38 (IO2)
unnamed: C20.1, R11.1
unnamed: J15.A5 (CC1), R15.1
unnamed: J15.B5 (CC2), R16.1
unnamed: J19.A5 (CC1), R17.1
unnamed: J19.B5 (CC2), R18.1
unnamed: M1.1 (-), Q3.2 (D)
unnamed: M2.1 (-), Q4.2 (D)
unnamed: Q1.4 (G), U7.13 (HO)
unnamed: C28.2, L2.1, Q1.1 (S), Q1.2 (S), Q1.3 (S), Q2.5 (D), U7.14 (SW)
unnamed: Q2.4 (G), U7.11 (LO)
unnamed: SW1.2 (B), U4.27 (IO0)
unnamed: R1.2, U1.14 (REXT)
unnamed: U1.3 (XIN), Y1.1
unnamed: U1.2 (XOUT), Y1.2
unnamed: R22.2, U1.17 (~XRSTJ)
unnamed: R19.1, U4.22 (IO14)
unnamed: R20.1, U4.8 (IO15)
unnamed: R6.2, U5.14 (REXT)
unnamed: U5.3 (XIN), Y3.1
unnamed: U5.2 (XOUT), Y3.2
unnamed: R5.2, U5.17 (~XRSTJ)
unnamed: R8.2, U6.14 (REXT)
unnamed: U6.3 (XIN), Y4.1
unnamed: U6.2 (XOUT), Y4.2
unnamed: R7.2, U6.17 (~XRSTJ)
unnamed: C28.1, U7.15 (CBOOT)
unnamed: R3.2, U7.3 (CNFG)
unnamed: C21.1, R11.2, U7.5 (EXTCOMP)
unnamed: R10.2, U7.6 (FB)
unnamed: L2.2, R12.2, U7.20 (ISNS+)
unnamed: C22.1, R10.1, U7.8 (VDDA), U7.18 (PFM/SYNC)
unnamed: R9.2, U7.17 (PG/SYNCOUT)
unnamed: R4.1, U7.4 (RT)
unnamed: C17.2, R9.1, U7.9 (VCC)
RE_A: J11.1, R19.2
RE_B: J11.2, R20.2
RE_SW: J11.3, R21.2, U4.9 (IO16)
S1D+1: J21.1, U6.11 (DP1)
S1D+2: J21.3, U6.9 (DP2)
S1D+3: J10.1, U6.7 (DP3)
S1D+4: J10.3, U6.5 (DP4)
S1D-1: J21.2, U6.10 (DM1)
S1D-2: J21.4, U6.8 (DM2)
S1D-3: J10.2, U6.6 (DM3)
S1D-4: J10.4, U6.4 (DM4)
S1DRV: U4.6 (IO6), U6.22 (DRV)
S1LED1: U4.4 (IO4), U6.23 (LED1/EESCL)
S1LED2: U4.5 (IO5), U6.24 (LED2)
S2D+1: J19.A6 (D+), J19.B6 (D+), U4.14 (USB_D+), U5.11 (DP1)
S2D+2: J7.3 (D+), U5.9 (DP2)
S2D+3: J5.3 (D+), U5.7 (DP3)
S2D+4: J10.5, U5.5 (DP4)
S2D-1: J19.A7 (D-), J19.B7 (D-), U4.13 (USB_D-), U5.10 (DM1)
S2D-2: J7.2 (D-), U5.8 (DM2)
S2D-3: J5.2 (D-), U5.6 (DM3)
S2D-4: J10.6, U5.4 (DM4)
S2DRV: U4.17 (IO9), U5.22 (DRV)
S2LED1: U4.7 (IO7), U5.23 (LED1/EESCL)
S2LED2: U4.12 (IO8), U5.24 (LED2)
SW1: J11.4, U4.10 (IO17)
SW2: J11.5, U4.11 (IO18)
SW3: J11.6, U4.23 (IO21)

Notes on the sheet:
Consumed (DBR)
Consumed (self)
Daughterboard-F
Consumed (DBL)
Daughterboard-R
VCC GND DIN SCLK CS DC RST BUSY PWR
Daughterboard-L
Used internally
Mainboard USB-A outputs
E-Ink display (front)
Data IN
Connectors to Daughterboards
ESP32 + USB port for debugging
Power IN
PWM fans
LDOs (5V to 3V3) (5V to 1V8)
12V-5V buck

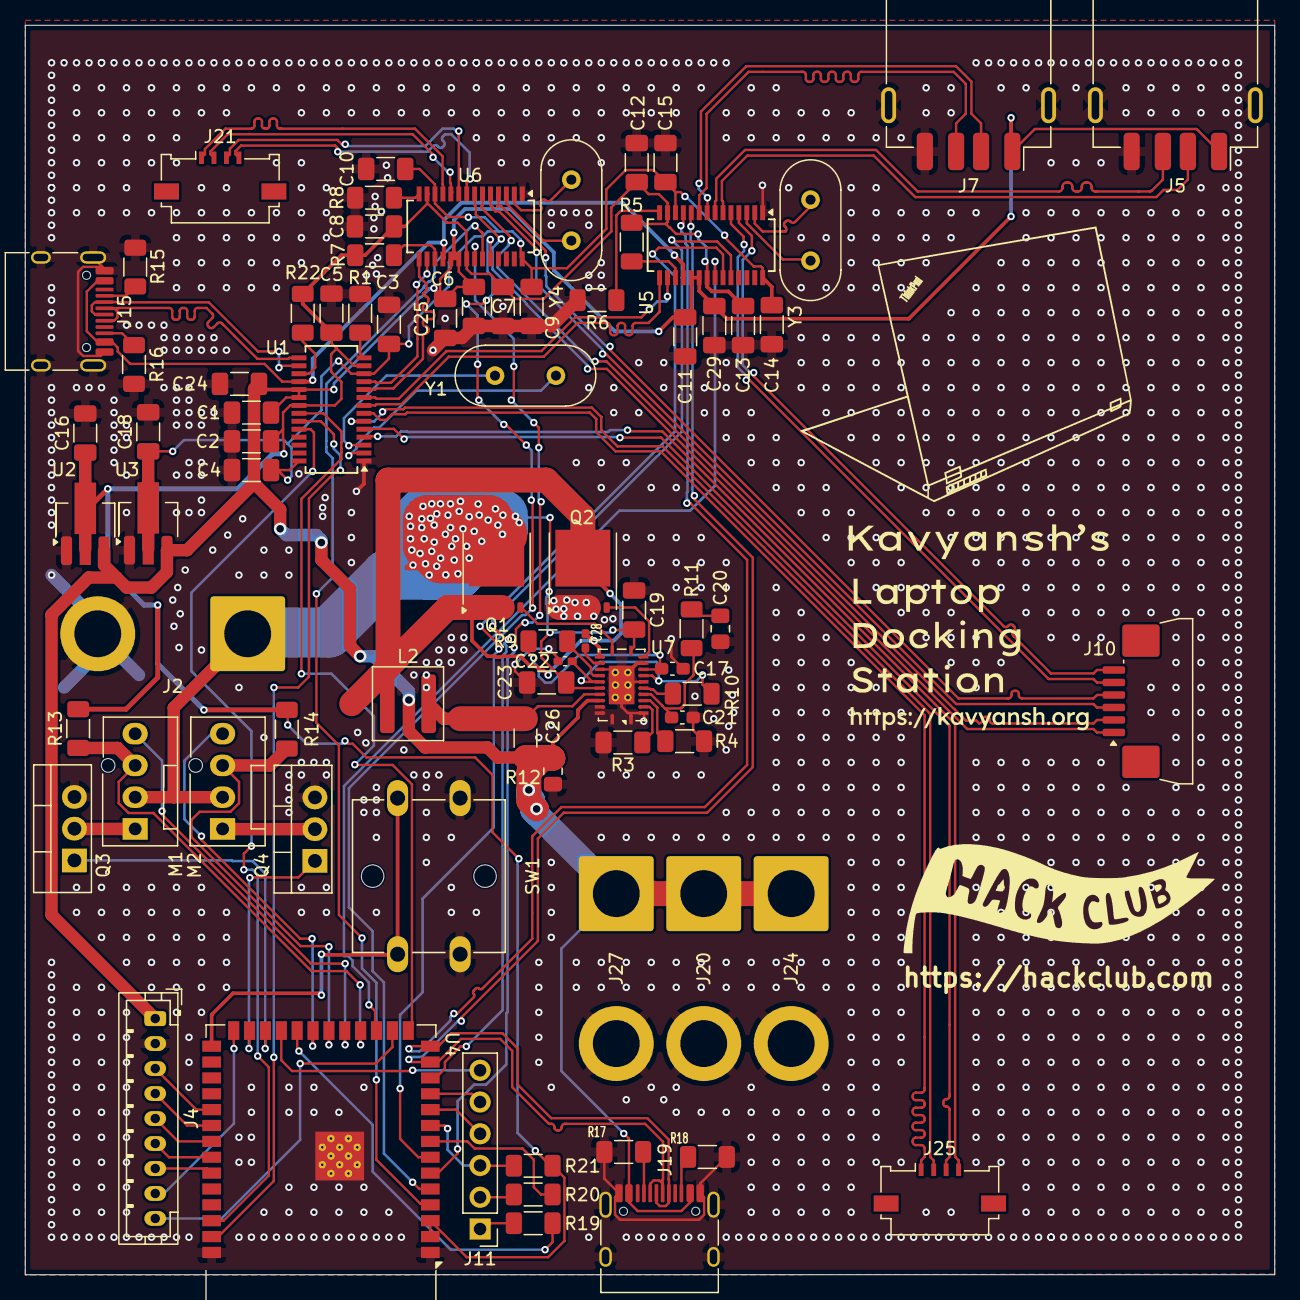
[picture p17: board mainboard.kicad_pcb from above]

Board: 2 copper layers, 100.0 x 100.0 mm, 80 parts (0 on the bottom side), 94 nets.

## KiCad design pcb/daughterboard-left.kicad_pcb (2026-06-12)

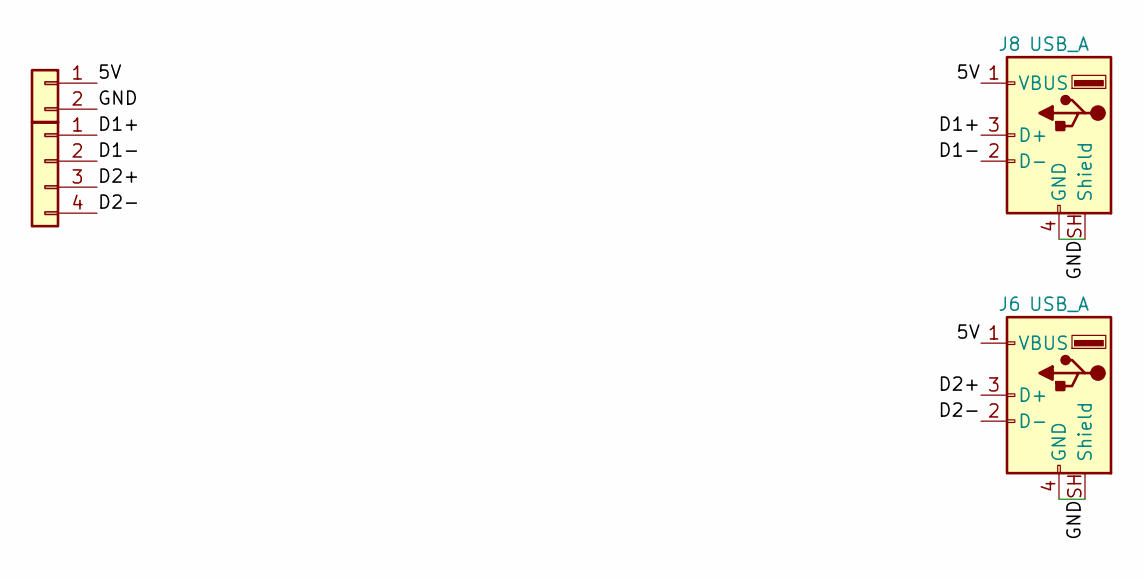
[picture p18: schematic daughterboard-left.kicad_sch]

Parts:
J6, J8: USB_A; USB_A_Receptacle_GCT_USB1046
J22: Conn_01x02; SolderWire-4sqmm_1x02_P12mm_D3mm_OD6mm
J23: Conn_01x04; Molex_200528-0040_1x04-1MP_P1.00mm_Horizontal

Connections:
/5V: J6.1 (VBUS), J8.1 (VBUS), J22.1
/D1+: J8.3 (D+), J23.1
/D1-: J8.2 (D-), J23.2
/D2+: J6.3 (D+), J23.3
/D2-: J6.2 (D-), J23.4
/GND: J6.4 (GND), J6.SH (Shield), J8.4 (GND), J8.SH (Shield), J22.2

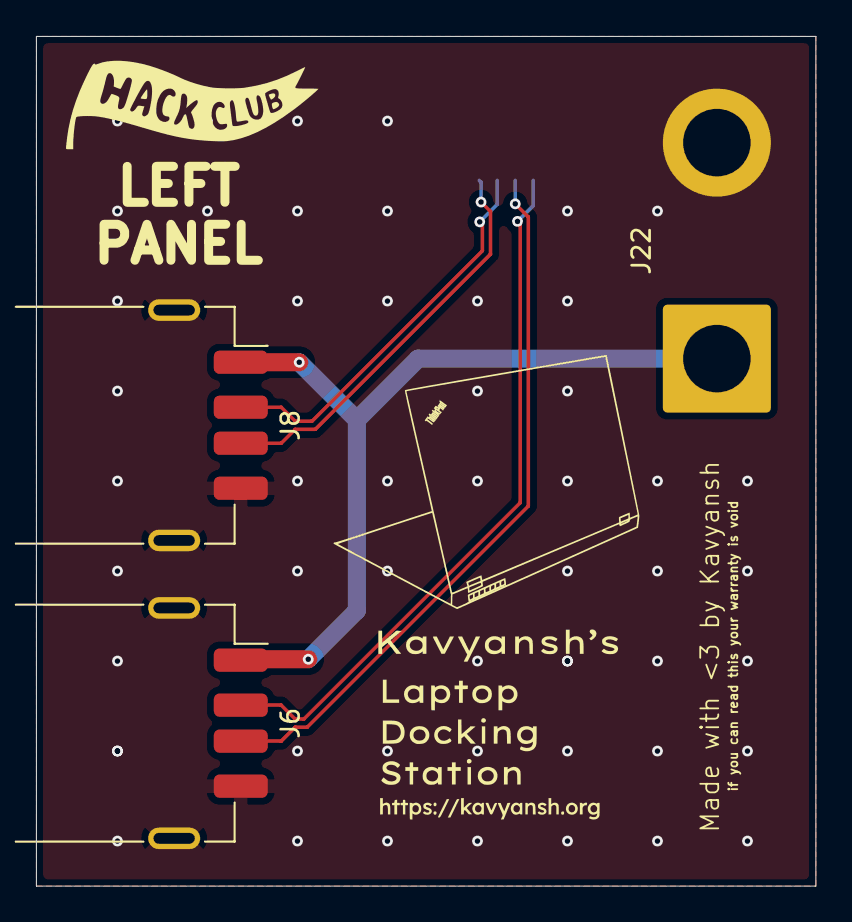
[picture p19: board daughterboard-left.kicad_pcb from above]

Board: 2 copper layers, 43.3 x 47.2 mm, 4 parts (1 on the bottom side), 6 nets.

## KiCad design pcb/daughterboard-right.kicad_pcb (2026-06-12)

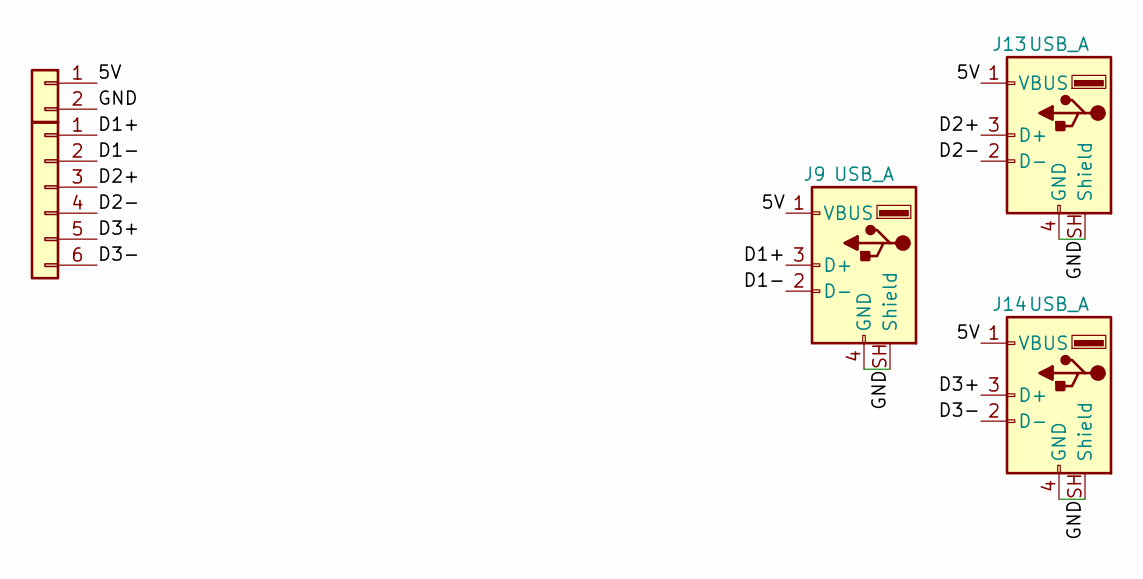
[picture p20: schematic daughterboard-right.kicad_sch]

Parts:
J9, J13, J14: USB_A; USB_A_Receptacle_GCT_USB1046
J12: Conn_01x06; JUSHUO_AFA07-S06FCA-00_1x6-1MP_P1.0mm_Horizontal
J30: Conn_01x02; SolderWire-4sqmm_1x02_P12mm_D3mm_OD6mm

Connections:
/5V: J9.1 (VBUS), J13.1 (VBUS), J14.1 (VBUS), J30.1
/D1+: J9.3 (D+), J12.1
/D1-: J9.2 (D-), J12.2
/D2+: J12.3, J13.3 (D+)
/D2-: J12.4, J13.2 (D-)
/D3+: J12.5, J14.3 (D+)
/D3-: J12.6, J14.2 (D-)
/GND: J9.4 (GND), J9.SH (Shield), J13.4 (GND), J13.SH (Shield), J14.4 (GND), J14.SH (Shield), J30.2

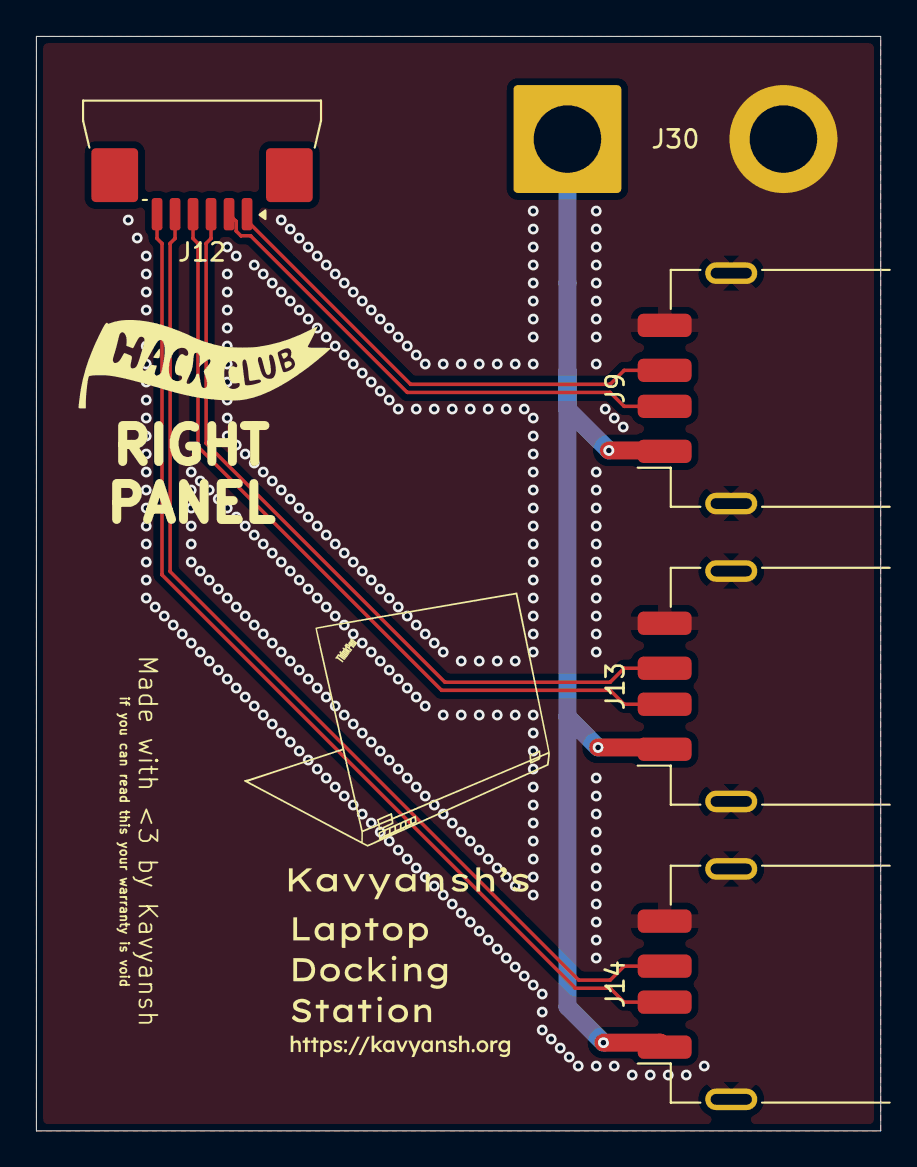
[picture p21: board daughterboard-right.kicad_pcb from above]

Board: 2 copper layers, 46.9 x 60.8 mm, 5 parts (0 on the bottom side), 8 nets.

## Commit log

2026-06-12 Add PCB
    [bom.csv, daughterboard-1.kicad_sch, daughterboard-front.kicad_pcb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]
2026-06-12 Remove .lck file from ./pcb
2026-06-12 Add production/3dp
    [Display angle-r - Part 1.stl, Main Case Thingy - Part 1.stl, Main Case Thingy - Part 2.stl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]
2026-06-13 Add BOM.csv
    [BOM.csv]
2026-06-13 Update README with PCB, Schematic, 3D, and BOM sections
    Added sections for PCB, Schematic, 3D models, and BOM with links.
2026-06-13 Add Bill of Materials section to README
